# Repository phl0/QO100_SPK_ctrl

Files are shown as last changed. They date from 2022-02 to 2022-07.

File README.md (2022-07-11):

# QO100_SPK_ctrl
Speaker control unit for full-duplex satellite operations for the sake of demonstration

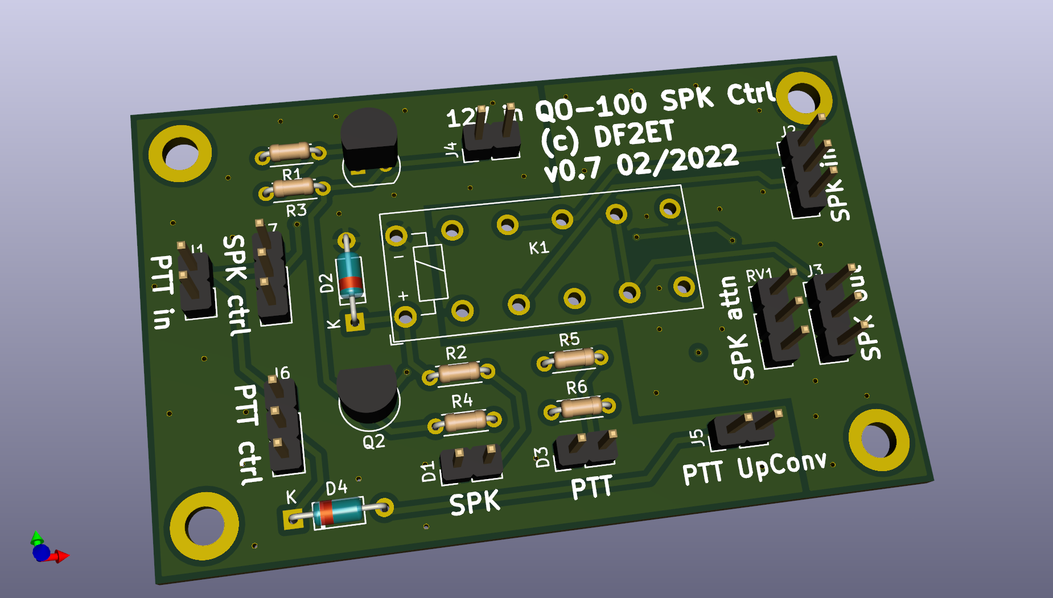
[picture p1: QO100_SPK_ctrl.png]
QO100_SPK_ctrl board


This circuit is designed to control the speaker level of a full-duplex satellite station during transmissions. It was originally designed to be used for a club station in order to demonstrate full-duplex satellite operations with audio output via speaker. In order to attenuate the audio level during transmissions to avoid feedback the audio line is attenuated with a 49-ohm potentiometer. The switching between RX and TX is done via PTT output of the TRX.

## Schematics

The [circuit schematics](QO100_SPK_ctrl.svg) is a simple relay switch using two PNP transistors. For manual control two switches are added so that the speaker attenuation as well as the PTT line of the UpConverter can be switched manually.

## Bill of Materials

The [few parts](QO100_SPK_ctrl.xlsx) can be grabbed from the spare parts box. For other purposes there is a shopping cart at German distributor Reichelt Eletronik. See [here](https://www.reichelt.de/my/1923061). This does not include the relay. Few of those can be obtained from the author. Same goes for the PCB itself. The LEDs as well as the trimmer are layouted as 2.54mm connectors so that the parts itself can be mounted in a case.

The [interactive BOM](https://www.df2et.de/QO100_SPK_ctrl/ibom.html) for sourcing and placing the parts can be found in the bom folder of this project.

## Known Issues

### v0.5
The v0.5 PCB and circuit were missing diode D4. Due to this the PTT transistor was pulled low by the UpConverter. This error has been corrected in v0.6.

### v0.6
The diode D4 has been added. This PCB rev is missing the 4 drill holes on the PCB edges.

### v0.7
The missing drill hole for mounting have been re-added.

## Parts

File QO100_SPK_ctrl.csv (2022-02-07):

Refs | Value | Footprint | Quantity | DESC | MFR | MPN | SPR | SPN | SPURL
J4 | 12V in | Connector_PinHeader_2.54mm:PinHeader_1x02_P2.54mm_Vertical | 1 | - | BKL | 10120919 | Reichelt | BKL 10120919 | https://www.reichelt.de/stiftleiste-2-54mm-1x2-h-12-6mm-gerade-bkl-10120919-p262783.html?trstct=pol_39&nbc=1
D3 | PTT | Connector_PinHeader_2.54mm:PinHeader_1x02_P2.54mm_Vertical | 1 | - | BKL | 10120919 | Reichelt | BKL 10120919 | https://www.reichelt.de/stiftleiste-2-54mm-1x2-h-12-6mm-gerade-bkl-10120919-p262783.html?trstct=pol_39&nbc=1
J5 | PTT UpConv | Connector_PinHeader_2.54mm:PinHeader_1x02_P2.54mm_Vertical | 1 | - | BKL | 10120919 | Reichelt | BKL 10120919 | https://www.reichelt.de/stiftleiste-2-54mm-1x2-h-12-6mm-gerade-bkl-10120919-p262783.html?trstct=pol_39&nbc=1
J1 | PTT in | Connector_PinHeader_2.54mm:PinHeader_1x02_P2.54mm_Vertical | 1 | - | BKL | 10120919 | Reichelt | BKL 10120919 | https://www.reichelt.de/stiftleiste-2-54mm-1x2-h-12-6mm-gerade-bkl-10120919-p262783.html?trstct=pol_39&nbc=1
D1 | SPK off | Connector_PinHeader_2.54mm:PinHeader_1x02_P2.54mm_Vertical | 1 | - | BKL | 10120919 | Reichelt | BKL 10120919 | https://www.reichelt.de/stiftleiste-2-54mm-1x2-h-12-6mm-gerade-bkl-10120919-p262783.html?trstct=pol_39&nbc=1
RV1 | 47R | Connector_PinHeader_2.54mm:PinHeader_1x03_P2.54mm_Vertical | 1 | - | - | P4W-LIN 47 | Reichelt |  | https://www.reichelt.de/hochlast-drahtpotentiometer-47-ohm-linear-6-mm-p4w-lin-47-p54289.html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
J6 | PTT ctrl | Connector_PinHeader_2.54mm:PinHeader_1x03_P2.54mm_Vertical | 1 | - | BKL | 10120200 | Reichelt | BKL 10120200 | https://www.reichelt.de/stiftleiste-3-polig-raster-2-54mm-bkl-10120200-p235647.html?trstct=vrt_pdn&nbc=1
J7 | SPK ctrl | Connector_PinHeader_2.54mm:PinHeader_1x03_P2.54mm_Vertical | 1 | - | BKL | 10120200 | Reichelt | BKL 10120200 | https://www.reichelt.de/stiftleiste-3-polig-raster-2-54mm-bkl-10120200-p235647.html?trstct=vrt_pdn&nbc=1
J2 | SPK in | Connector_PinHeader_2.54mm:PinHeader_1x03_P2.54mm_Vertical | 1 | - | BKL | 10120200 | Reichelt | BKL 10120200 | https://www.reichelt.de/stiftleiste-3-polig-raster-2-54mm-bkl-10120200-p235647.html?trstct=vrt_pdn&nbc=1
J3 | SPK out | Connector_PinHeader_2.54mm:PinHeader_1x03_P2.54mm_Vertical | 1 | - | BKL | 10120200 | Reichelt | BKL 10120200 | https://www.reichelt.de/stiftleiste-3-polig-raster-2-54mm-bkl-10120200-p235647.html?trstct=vrt_pdn&nbc=1
D2;D4 | 1N4148 | Diode_THT:D_DO-35_SOD27_P7.62mm_Horizontal | 2 | - | RND | RND 1N4148 | Reichelt | RND 1N4148 | https://www.reichelt.de/schalt-diode-100-v-200-ma-do-35-rnd-1n4148-p223368.html?&trstct=pos_1&nbc=1
Q1;Q2 | BC557B | Package_TO_SOT_THT:TO-92 | 2 | - | CDIL | BC 557B | Reichelt | BC 557B | https://www.reichelt.de/bipolartransistor-pnp-45v-0-1a-0-5w-to-92-bc-557b-p35845.html?trstct=pos_0&nbc=1
K1 | SDS S2 12V | QO100_SPK_ctrl:Relay_SDS_S2 | 1 | Relay | Panasonic | S2-DC12V | Farnell | 1175722 | https://de.farnell.com/panasonic/s2-12vdc/relais-2no-2nc-250vac-30vdc-4a/dp/1175722
R3;R6 | 10k | Resistor_THT:R_Axial_DIN0204_L3.6mm_D1.6mm_P5.08mm_Horizontal | 2 | - | - | 1/4W 10K | Reichelt | 1/4W 10K | https://www.reichelt.de/widerstand-kohleschicht-10-kohm-0207-250-mw-5--1-4w-10k-p1338.html?trstct=pol_4&nbc=1
R2;R5 | 1k | Resistor_THT:R_Axial_DIN0204_L3.6mm_D1.6mm_P5.08mm_Horizontal | 2 | - | - | 1/4W 1,0K | Reichelt | 1/4W 1,0K | https://www.reichelt.de/widerstand-kohleschicht-1-0-kohm-0207-250-mw-5--1-4w-1-0k-p1315.html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
R1;R4 | 4k7 | Resistor_THT:R_Axial_DIN0204_L3.6mm_D1.6mm_P5.08mm_Horizontal | 2 | - | - | 1/4W 4,7K | Reichelt | 1/4W 4,7K | https://www.reichelt.de/widerstand-kohleschicht-4-7-kohm-0207-250-mw-5--1-4w-4-7k-p1425.html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

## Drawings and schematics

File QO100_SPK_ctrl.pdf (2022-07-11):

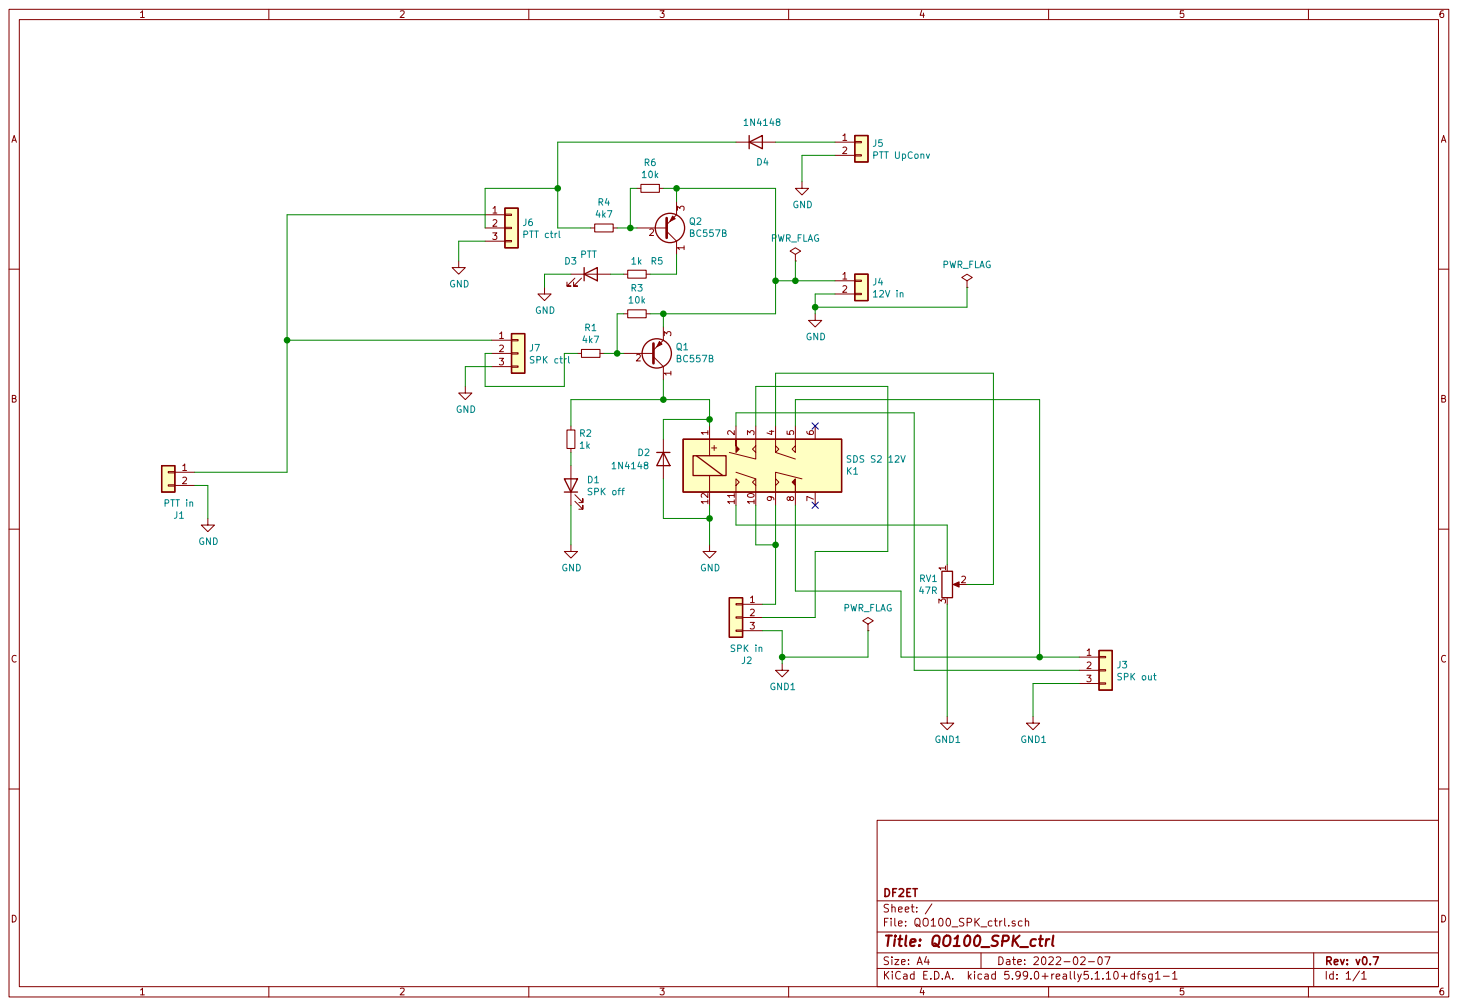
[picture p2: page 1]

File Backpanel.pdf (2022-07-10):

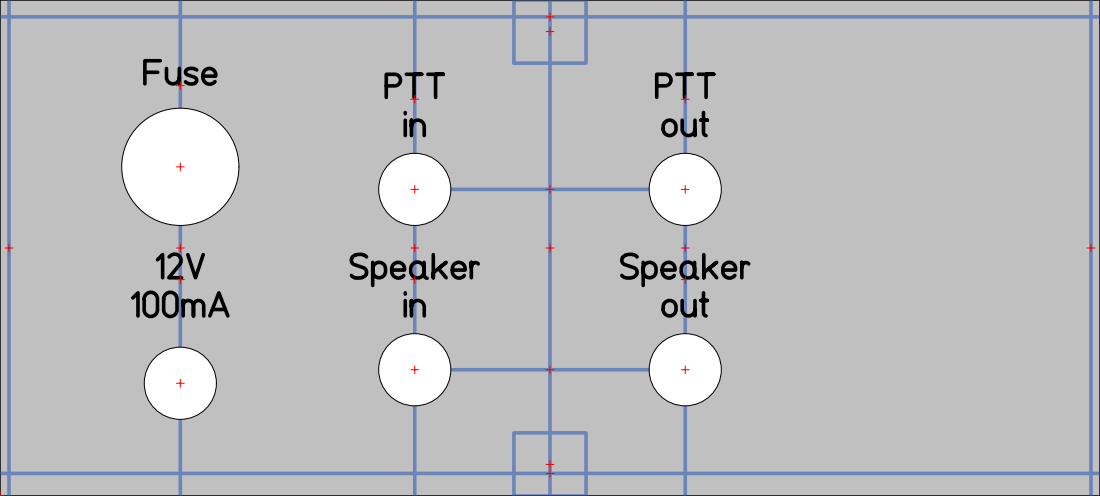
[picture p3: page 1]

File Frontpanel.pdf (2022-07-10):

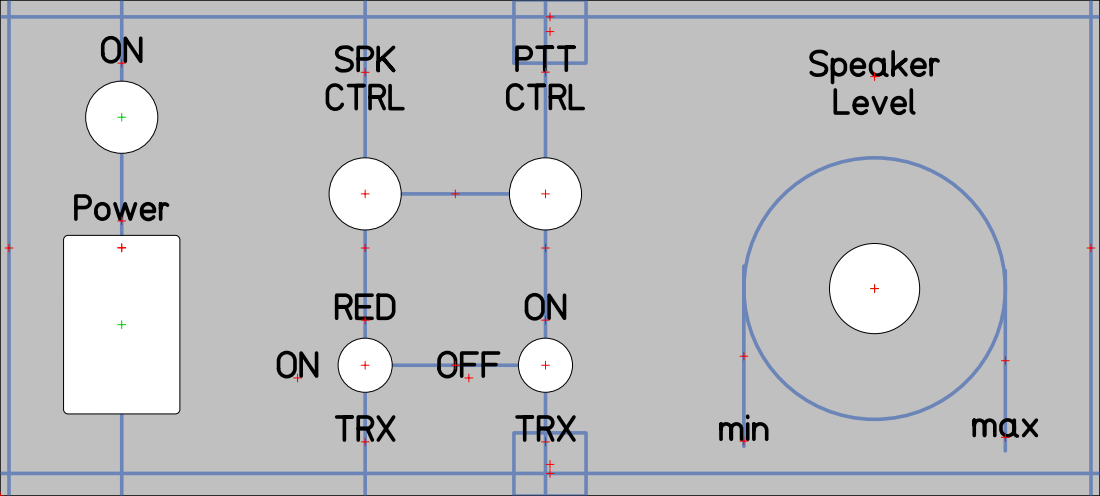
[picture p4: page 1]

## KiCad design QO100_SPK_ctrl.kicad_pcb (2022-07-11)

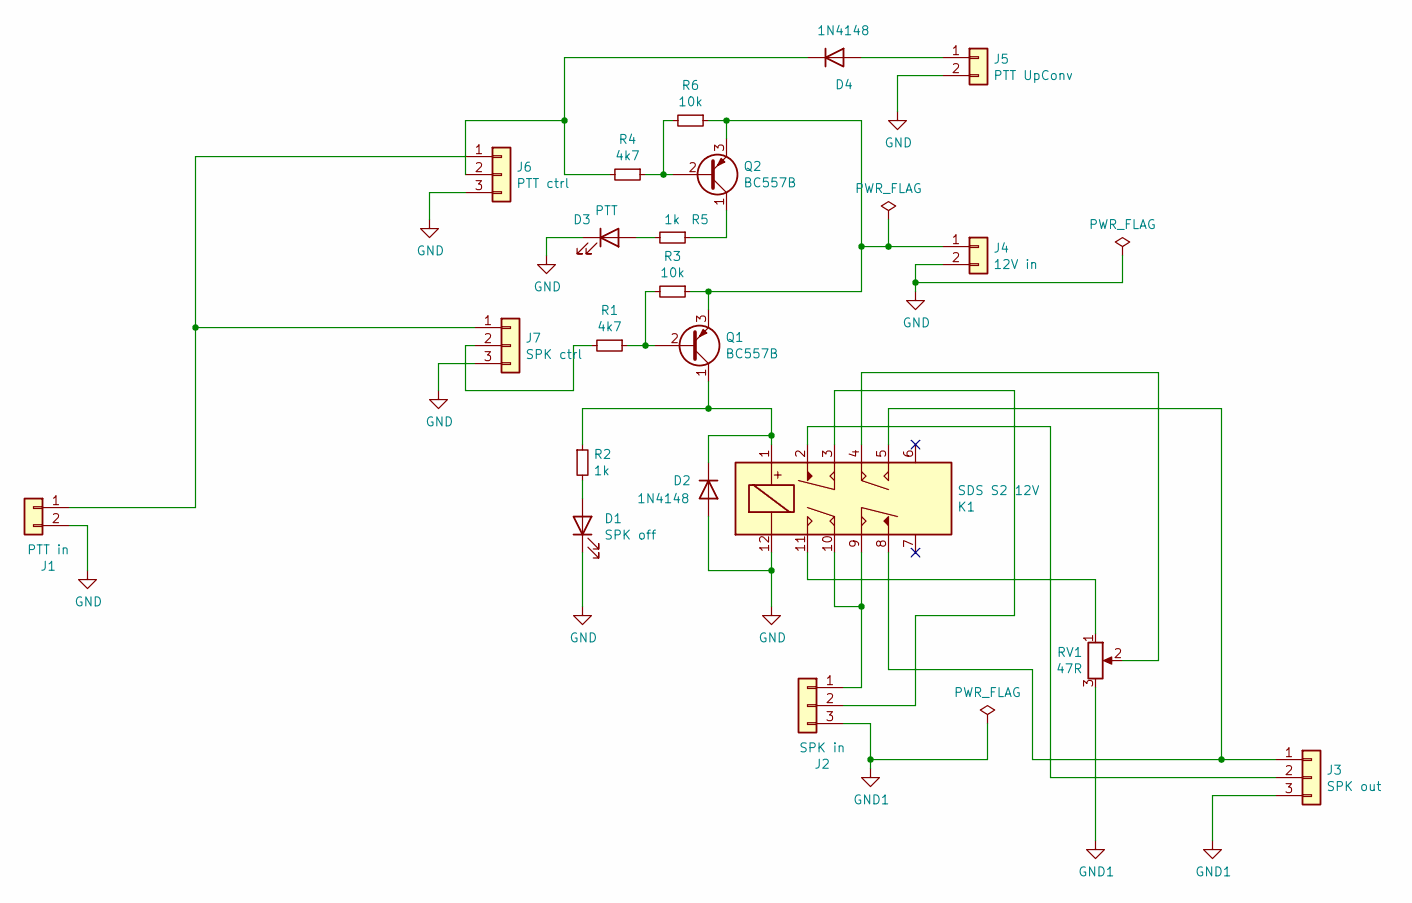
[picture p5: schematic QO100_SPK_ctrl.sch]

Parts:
D1: SPK off; PinHeader_1x02_P2.54mm_Vertical; MPN 10120919
D2, D4: 1N4148; D_DO-35_SOD27_P7.62mm_Horizontal; MPN RND 1N4148
D3: PTT; PinHeader_1x02_P2.54mm_Vertical; MPN 10120919
J1: PTT in; PinHeader_1x02_P2.54mm_Vertical; MPN 10120919
J2: SPK in; PinHeader_1x03_P2.54mm_Vertical; MPN 10120200
J3: SPK out; PinHeader_1x03_P2.54mm_Vertical; MPN 10120200
J4: 12V in; PinHeader_1x02_P2.54mm_Vertical; MPN 10120919
J5: PTT UpConv; PinHeader_1x02_P2.54mm_Vertical; MPN 10120919
J6: PTT ctrl; PinHeader_1x03_P2.54mm_Vertical; MPN 10120200
J7: SPK ctrl; PinHeader_1x03_P2.54mm_Vertical; MPN 10120200
K1: SDS S2 12V; Relay_SDS_S2; MPN S2-DC12V
Q1, Q2: BC557B; TO-92; MPN BC 557B
R1, R4: 4k7; R_Axial_DIN0204_L3.6mm_D1.6mm_P5.08mm_Horizontal; MPN 1/4W 4,7K
R2, R5: 1k; R_Axial_DIN0204_L3.6mm_D1.6mm_P5.08mm_Horizontal; MPN 1/4W 1,0K
R3, R6: 10k; R_Axial_DIN0204_L3.6mm_D1.6mm_P5.08mm_Horizontal; MPN 1/4W 10K
RV1: 47R; PinHeader_1x03_P2.54mm_Vertical; MPN P4W-LIN 47

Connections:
GND: D1.1 (K), D2.2 (A), D3.1 (K), J1.2, J4.2, J5.2, J6.3, J7.3, K1.12
GND1: J2.3, J3.3, RV1.3
unnamed: D1.2 (A), R2.2
unnamed: D2.1 (K), K1.1, Q1.1 (C), R2.1
unnamed: D3.2 (A), R5.2
unnamed: D4.1 (K), J6.2, R4.2
unnamed: D4.2 (A), J5.1
unnamed: J1.1, J6.1, J7.1
unnamed: J2.1, K1.9, K1.10
unnamed: J2.2, K1.3
unnamed: J3.1, K1.5, K1.8
unnamed: J3.2, K1.2
unnamed: J4.1, Q1.3 (E), Q2.3 (E), R3.1, R6.1
unnamed: J7.2, R1.2
unnamed: K1.4, RV1.2
unnamed: K1.11, RV1.1
unnamed: Q1.2 (B), R1.1, R3.2
unnamed: Q2.1 (C), R5.1
unnamed: Q2.2 (B), R4.1, R6.2

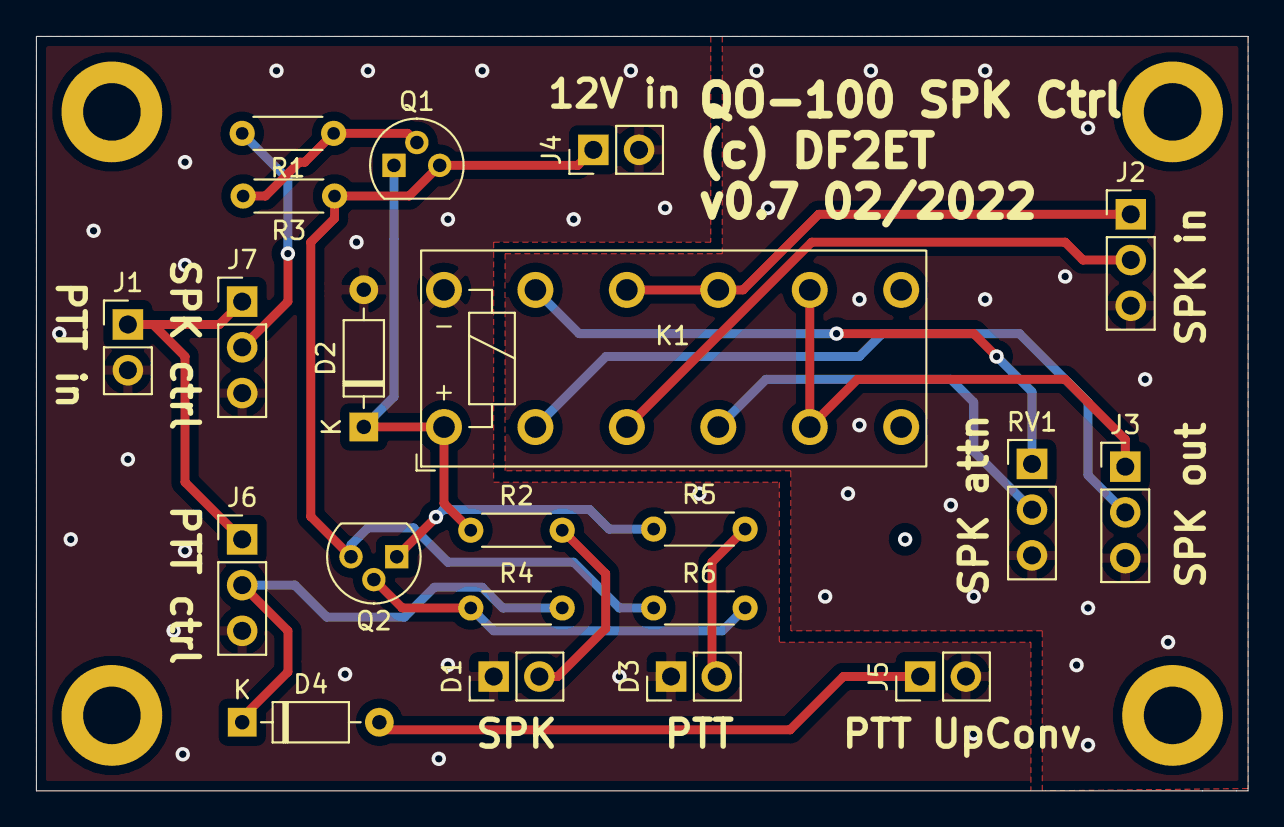
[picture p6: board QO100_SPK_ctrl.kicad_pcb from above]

Board: 2 copper layers, 67.3 x 41.9 mm, 21 parts (0 on the bottom side), 19 nets.

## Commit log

2022-02-07 Re-add drill holes for mounting
    [QO100_SPK_ctrl.kicad_pcb, QO100_SPK_ctrl.sch]
2022-02-07 Update ibom
    [QO100_SPK_ctrl.kicad_pcb]
